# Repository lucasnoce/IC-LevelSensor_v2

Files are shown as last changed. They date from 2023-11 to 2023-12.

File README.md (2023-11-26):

# IC-LevelSensor_v2
This is version 2 of an IoT device designed to measure water levels using an ultrasonic sensing module and transmit the acquired data via NBIoT.

## Summary
Similar to version 1, the system employs an AJ-SR04M ultrasonic sensing module now connected to a STM32L476RGT6 microcontroller. This module measures the time interval it takes for an ultrasonic wave to travel from the transducer to the water level and back. By calculating the distance based on the time duration, the speed of sound, and dividing the result by 2, the accurate water level is determined. As the speed of sound varies based on factors such as temperature, humidity, and pressure, a SHT31-DIS sensor is incorporated to measure temperature and humidity (pressure is assumed constant). This additional information allows for precise estimation of the speed of sound just before each distance measurement is taken.

To transmit data to the TagoIO platform, a SIM7020 NBIoT module is utilized, employing the MQTT protocol. This facilitates the configuration of a comprehensive dashboard displaying variations in water and battery levels, local temperature and humidity over time, making it an excellent solution for monitoring purposes.

The device is specifically designed for deployment in remote environments and operates on battery power. Due to this constraint, the system primarily operates in low-power mode and wakes up periodically. In this initial version of the device, the wake-up period is intentionally kept small, and collected data is transmitted during each wake-up event via NBIoT. This design choice aims to facilitate easier debugging and testing of the device's functionality. Because it is designed to be battery powered, the device can monitor battery voltage through the microcontroller's ADC.

## Designed PCB
The following image shows the designed PCB layout. It incorporates the SMT32, SHT31, SIM7020E and its adjacent circuitry onto the layout, only leaving the AJ-SR04M as an external module. The PCB features a P-Channel MOSFET at power input for low power reverse polarity protection, a selectable current sensing shunt resistor and ESD protection on the USB connector, SIM Card socket and SIM7020 power input tantalum capacitors. Also features IPEX connector for external antenna with impedance matched trace. The board works on 3.3V and can be powered either by 1.5V batteries such as AAA (through TPS613221ADBV DC-DC boost converter) or by the Micro USB type B (through AMS1117-3.3 regulator).

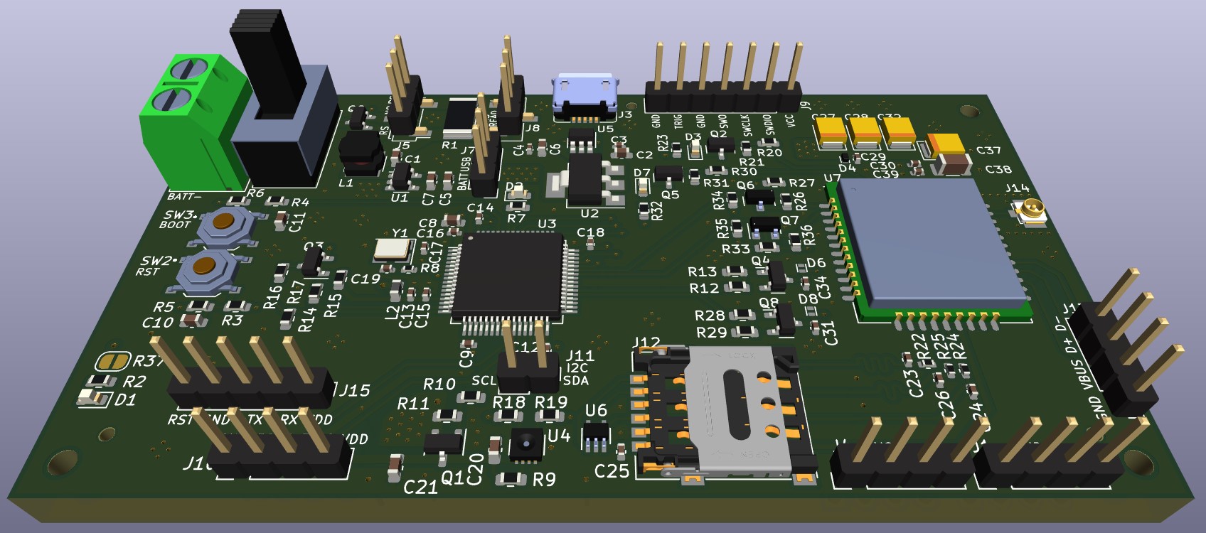
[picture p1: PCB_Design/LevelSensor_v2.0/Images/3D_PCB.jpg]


## Software
Still under development, all drivers and functionalities will be implemented from scratch through STM32CubeIDE.

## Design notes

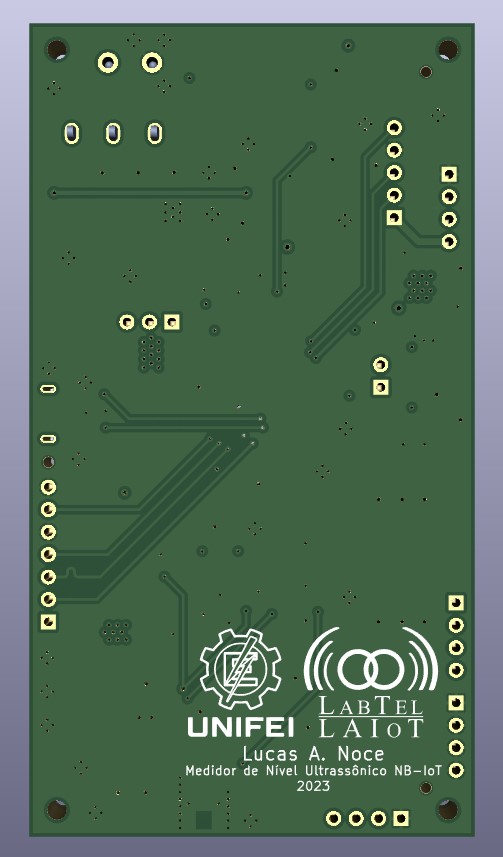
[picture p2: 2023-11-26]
PCB_Design/LevelSensor_v2.0/Images/3D_PCB_back.jpg

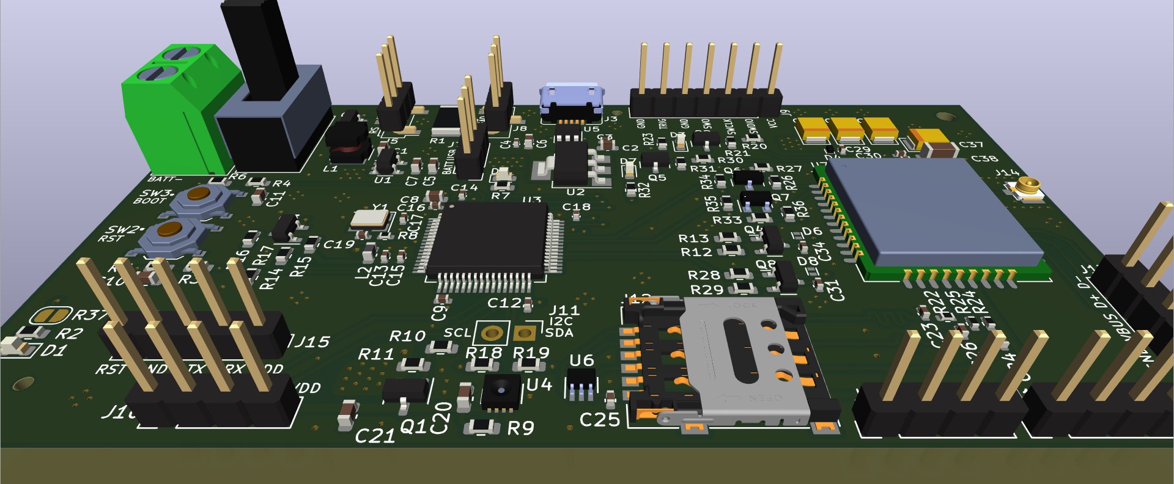
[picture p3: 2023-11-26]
PCB_Design/LevelSensor_v2.0/Images/3D_PCB_2.jpg

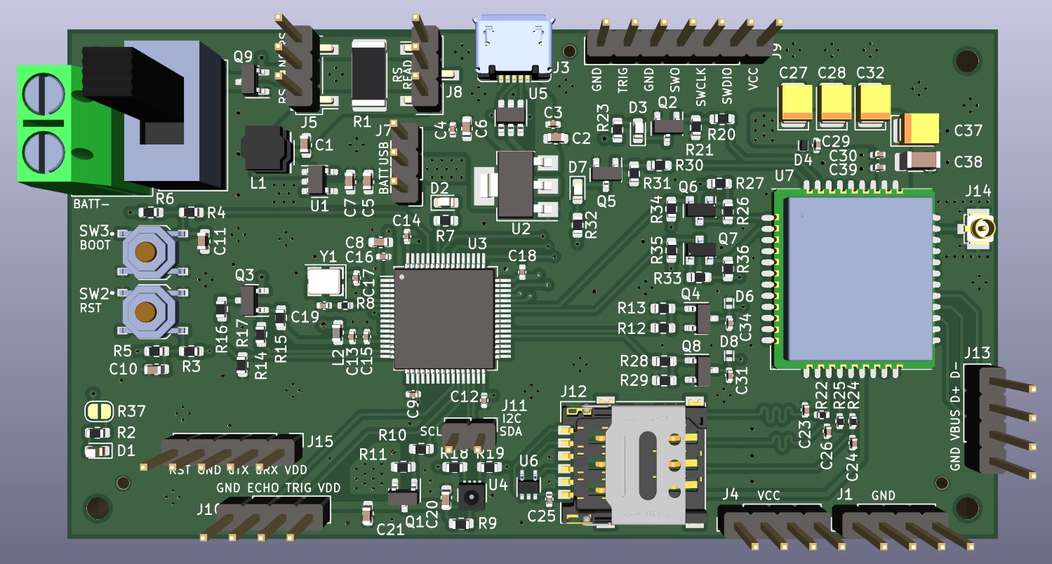
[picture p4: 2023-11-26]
PCB_Design/LevelSensor_v2.0/Images/3D_PCB_front.jpg

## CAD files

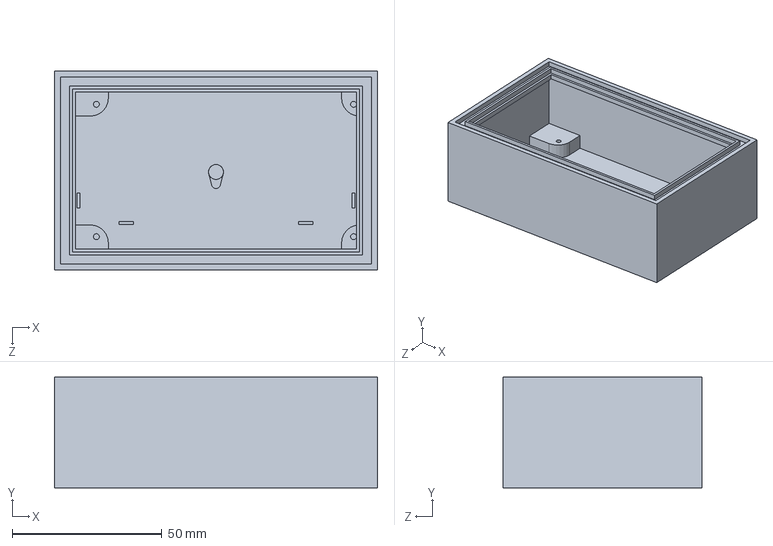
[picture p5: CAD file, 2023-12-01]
3D_Case/Caixa_v1.SLDPRT
108.0 x 37.0 x 66.4 mm

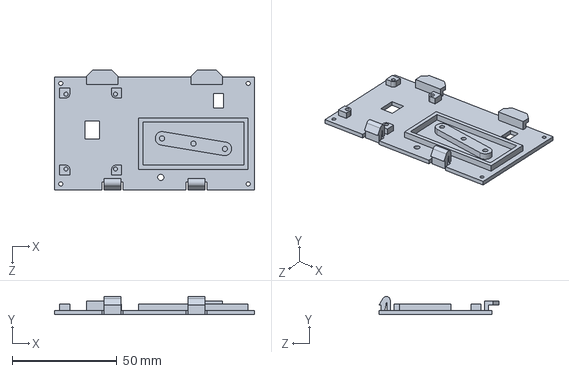
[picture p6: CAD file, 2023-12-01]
3D_Case/Tampa_v1.SLDPRT
95.5 x 8.66 x 57.5 mm

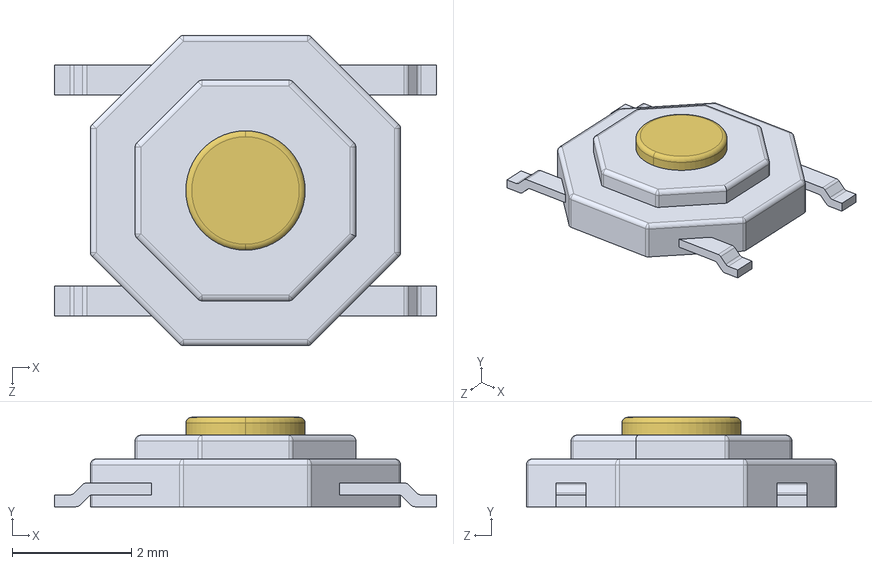
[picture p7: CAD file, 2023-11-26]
PCB_Design/LevelSensor_v2.0/3D_Models/Push-button_SMD_SKQGAFE010.STEP
6.40 x 1.50 x 5.20 mm

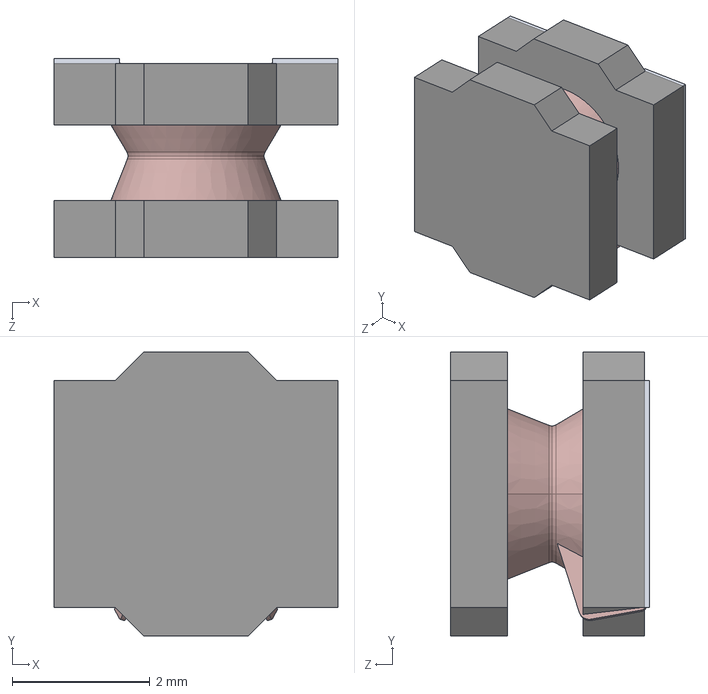
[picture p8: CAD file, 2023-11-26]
PCB_Design/LevelSensor_v2.0/3D_Models/L_FNR4030S2R2MT.STEP
4.12 x 4.12 x 2.89 mm

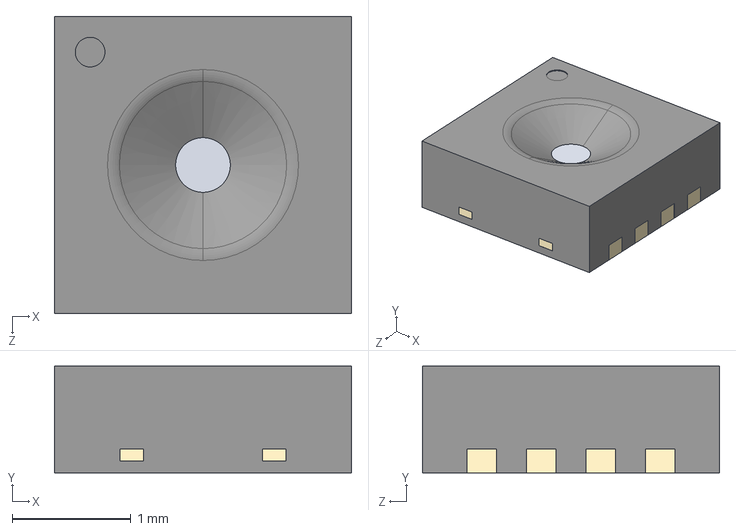
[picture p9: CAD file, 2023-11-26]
PCB_Design/LevelSensor_v2.0/3D_Models/SHT31-DIS_DFN-8.STEP
2.50 x 0.9 x 2.50 mm

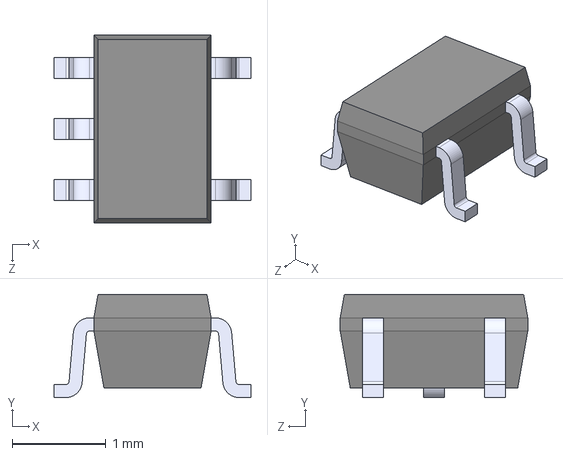
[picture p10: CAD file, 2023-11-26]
PCB_Design/LevelSensor_v2.0/3D_Models/ESDA6V1W5--3DModel-STEP-56544.STEP
2.10 x 1.10 x 2.00 mm

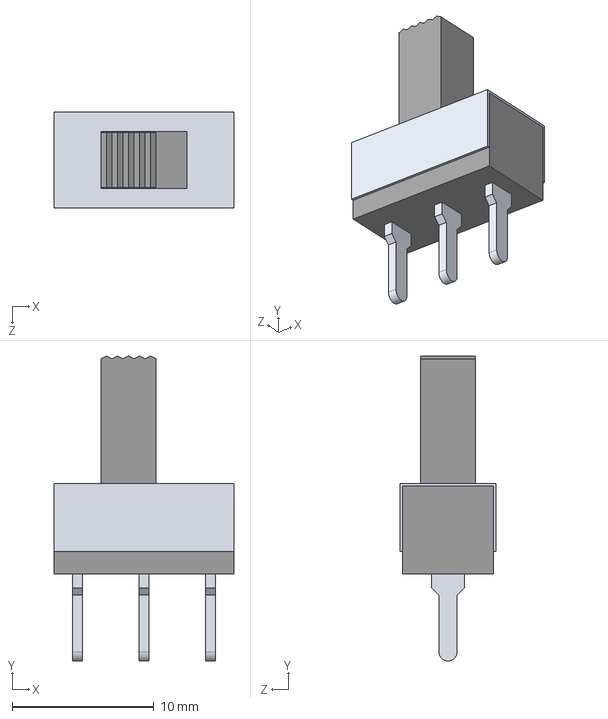
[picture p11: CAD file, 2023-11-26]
PCB_Design/LevelSensor_v2.0/3D_Models/SPDT.STEP
12.7 x 21.5 x 6.80 mm

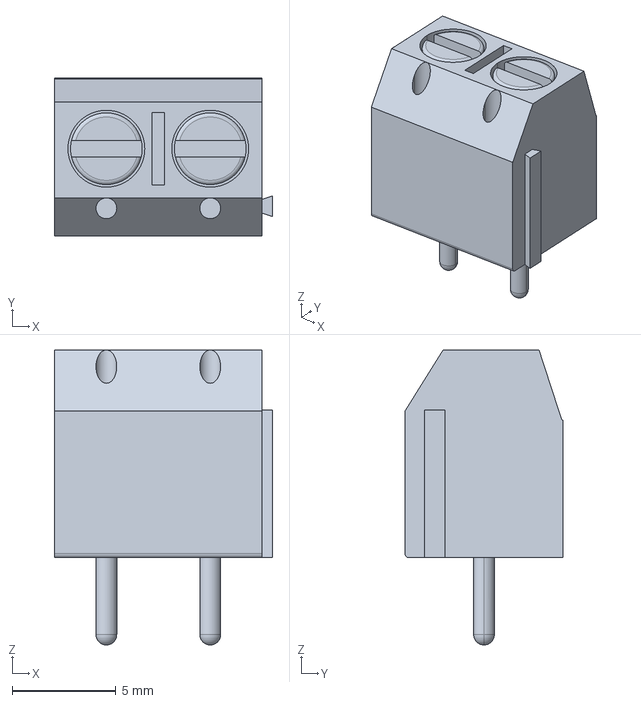
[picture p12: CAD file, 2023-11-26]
PCB_Design/LevelSensor_v2.0/3D_Models/RND 205-301-5.0-02P--3DModel-STEP-697569.STEP
10.5 x 7.60 x 14.2 mm

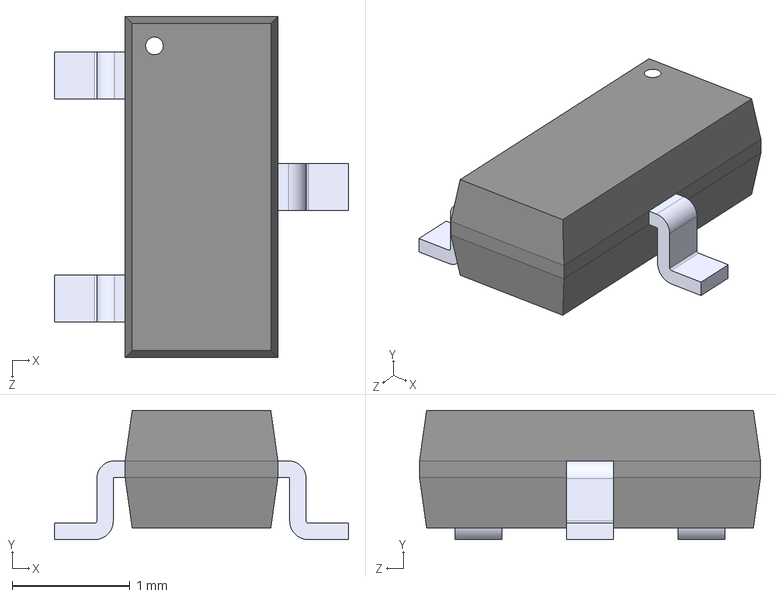
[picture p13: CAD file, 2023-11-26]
PCB_Design/LevelSensor_v2.0/3D_Models/MMBT3904.STEP
2.50 x 1.10 x 2.90 mm

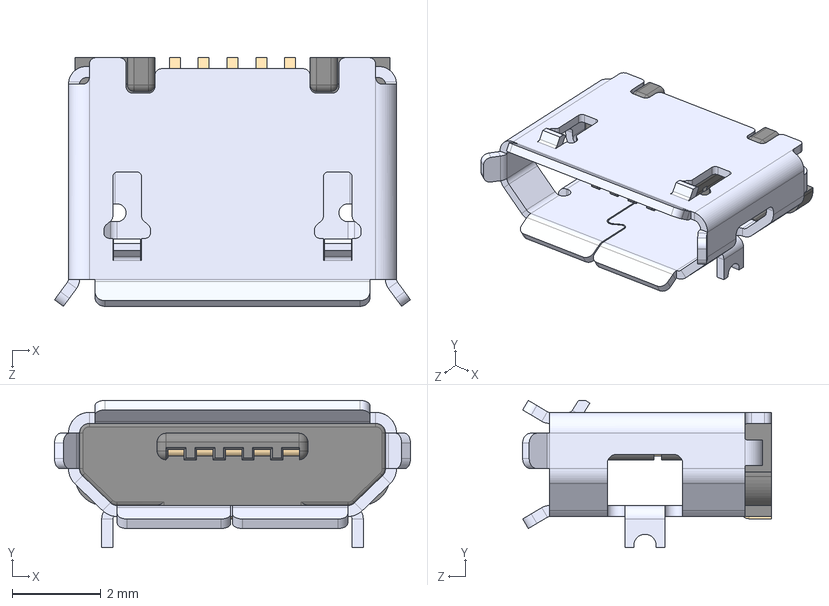
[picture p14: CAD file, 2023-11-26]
PCB_Design/LevelSensor_v2.0/3D_Models/USB-MR-D-015--3DModel-STEP-269445.STEP
8.03 x 3.32 x 5.61 mm

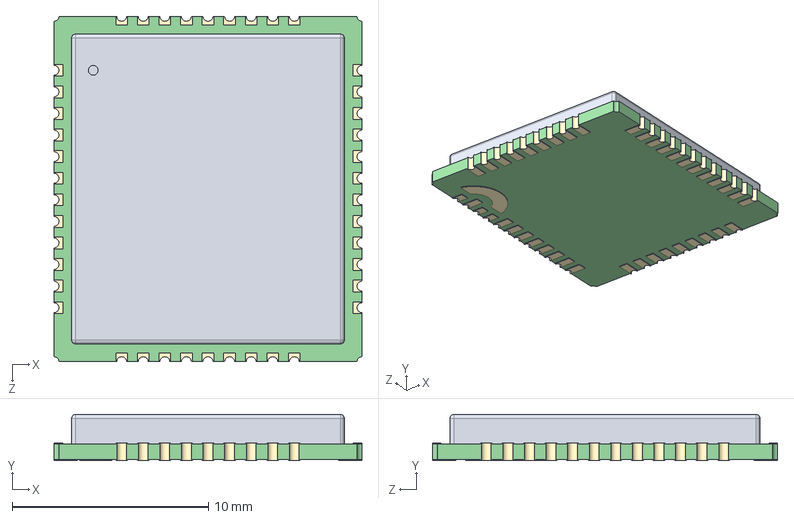
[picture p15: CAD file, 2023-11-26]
PCB_Design/LevelSensor_v2.0/3D_Models/SIM7020E.STEP
15.7 x 2.35 x 17.6 mm

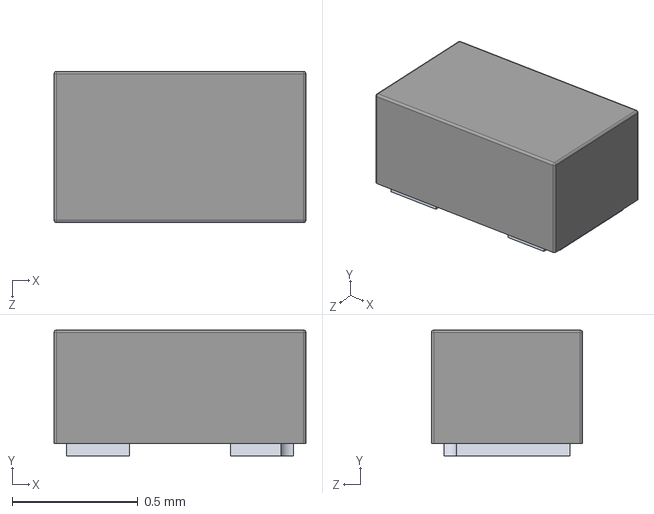
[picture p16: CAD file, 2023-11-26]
PCB_Design/LevelSensor_v2.0/3D_Models/DFN1006-2L.STEP
1.00 x 0.5 x 0.6 mm

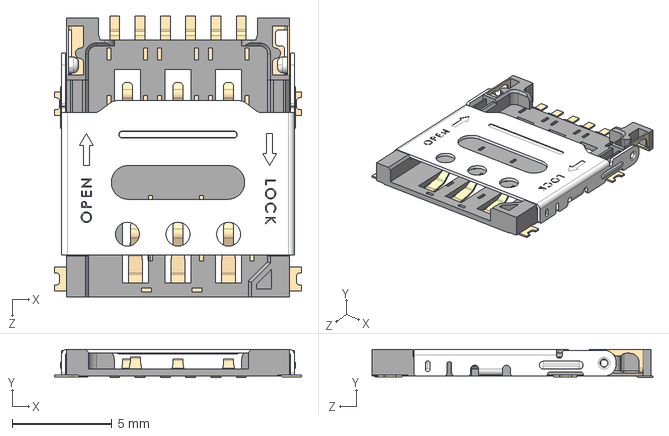
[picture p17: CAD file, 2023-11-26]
PCB_Design/LevelSensor_v2.0/3D_Models/sim8060-6-0-14-00-a_reva.step
12.4 x 1.43 x 14.1 mm
Housing1_without switch

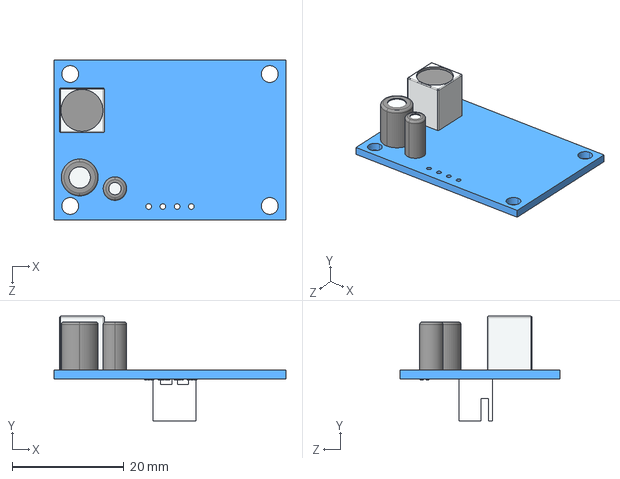
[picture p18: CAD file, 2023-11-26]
PCB_Design/LevelSensor_v2.0/3D_Models/AJ-SR04M.STEP
41.5 x 18.7 x 28.6 mm

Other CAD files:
PCB_Design/LevelSensor_v2.0/3D_Models/RND 205-301-5.0-02P--3DModel-STEP-697569_col.STEP
PCB_Design/LevelSensor_v2.0/3D_Models/10118192C.stp

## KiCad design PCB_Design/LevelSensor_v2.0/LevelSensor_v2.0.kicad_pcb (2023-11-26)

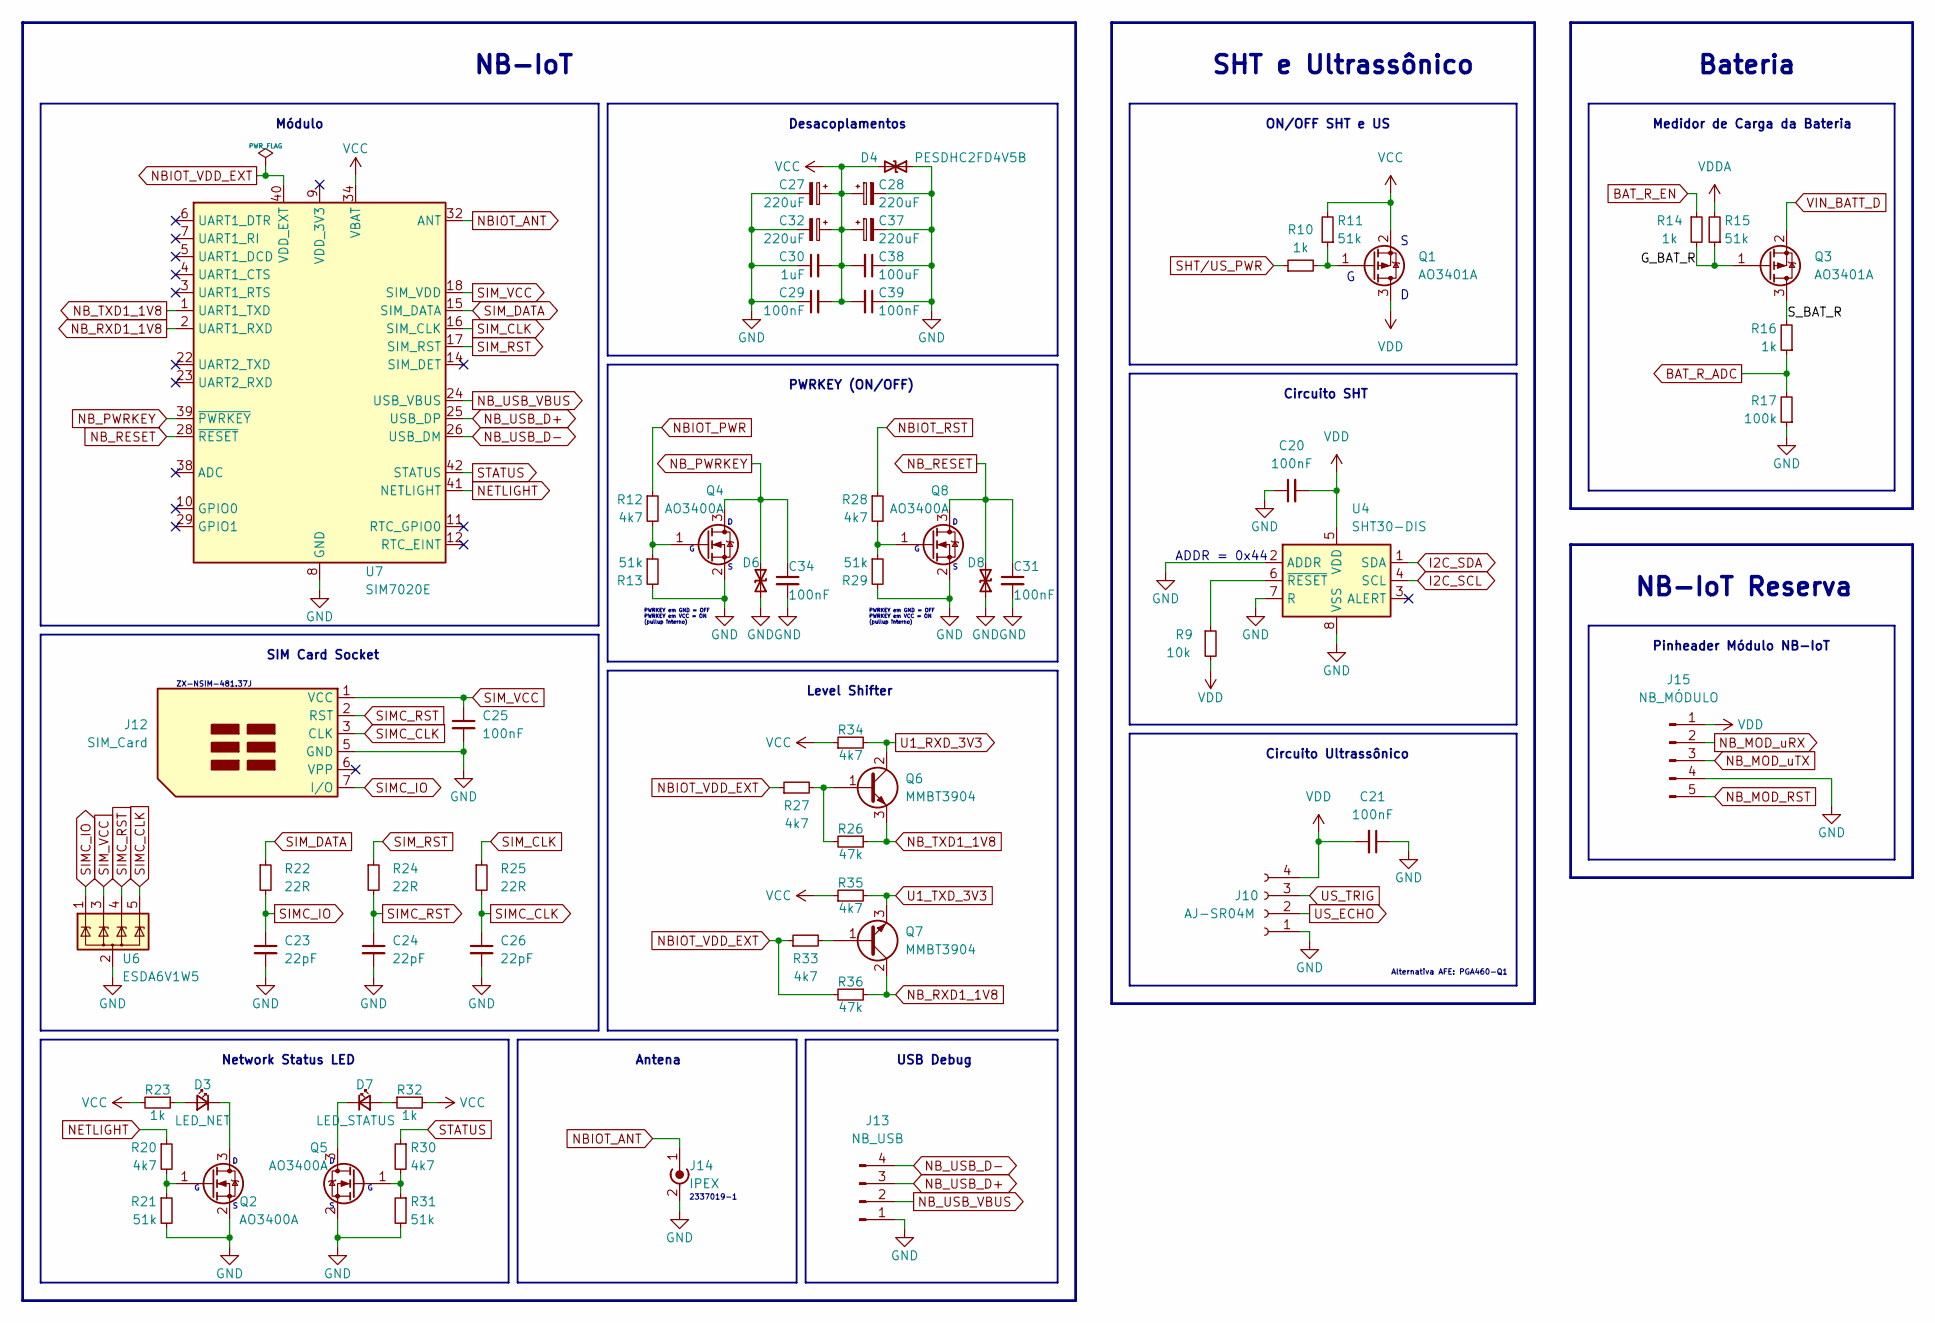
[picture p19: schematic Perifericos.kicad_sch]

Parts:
C20, C21: 100nF; C_0603_1608Metric; LCSC Part Number C14663
C23, C24, C26: 22pF; C_0402_1005Metric; LCSC Part Number C1555
C25, C29, C31, C34, C39: 100nF; C_0402_1005Metric; LCSC Part Number C1525
C27, C28, C32, C37: 220uF; CP_EIA-3528-12_Kemet-T
C30: 1uF; C_0402_1005Metric; LCSC Part Number C52923
C38: 100uF; C_1206_3216Metric; LCSC Part Number C15008
D3: LED_NET; LED_0603_1608Metric; LCSC Part Number C2286
D4, D6, D8: PESDHC2FD4V5B; D_TVS_DFN1006-2L
D7: LED_STATUS; LED_0603_1608Metric; LCSC Part Number C72041
J10: AJ-SR04M
J12: SIM_Card; NanoSIMCard-Socket_ZX-NSIM-281.4J
J13: NB_USB; PinHeader_1x04_P2.54mm_Vertical
J14: IPEX; Conn_RF_Receptacle_SMT-TE_2337019-1
J15: NB_MÓDULO; PinHeader_1x05_P2.54mm_Vertical
Q1, Q3: AO3401A; SOT-23; LCSC Part Number C15127
Q2, Q4, Q5, Q8: AO3400A; SOT-23; LCSC Part Number C20917
Q6, Q7: MMBT3904; TBJ_SOT-23; LCSC Part Number C20526
R9: 10k; R_0603_1608Metric; LCSC Part Number C25804
R10, R14, R16, R23, R32: 1k; R_0603_1608Metric; LCSC Part Number C21190
R11, R13, R15, R21, R29, R31: 51k; R_0603_1608Metric; LCSC Part Number C23196
R12, R20, R27, R28, R30, R33, R34, R35: 4k7; R_0603_1608Metric; LCSC Part Number C23162
R17: 100k; R_0603_1608Metric; LCSC Part Number C25803
R22, R24, R25: 22R; R_0402_1005Metric; LCSC Part Number C25092
R26, R36: 47k; R_0603_1608Metric; LCSC Part Number C25819
U4: SHT30-DIS; Sensirion_DFN-8-1EP_2.5x2.5mm_P0.5mm_EP1.1x1.7mm; LCSC Part Number C2687423
U6: ESDA6V1W5; SOT323-5L; LCSC Part Number C167129
U7: SIM7020E; SIMCom_SIM800C; LCSC Part Number C194746

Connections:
/Perifericos/G_BAT_R: Q3.1 (G), R14.2, R15.1
/Perifericos/S_BAT_R: Q3.3 (D), R16.2
BAT_R_ADC: R16.1, R17.2; also elsewhere on the board
BAT_R_EN: R14.1; also elsewhere on the board
GND: C20.1, C21.1, C23.2, C24.2, C25.2, C26.2, C27.2, C28.2, C29.1, C30.1, C31.2, C32.2, C34.2, C37.2, C38.1, C39.1, D4.1 (A1), D6.1 (A1), D8.1 (A1), J10.1, J12.5 (GND), J13.1, J14.2 (Ext), J15.4, Q2.2 (S), Q4.2 (S), Q5.2 (S), Q8.2 (S), R13.2, R17.1, R21.2, R29.2, R31.2, U4.2 (ADDR), U4.7 (R), U4.8 (VSS), U4.9 (VSS), U6.2 (GND), U7.8 (GND), U7.13 (GND), U7.19 (GND), U7.21 (GND), U7.27 (GND), U7.30 (GND), U7.31 (GND), U7.33 (GND), U7.36 (GND), U7.37 (GND); also elsewhere on the board
I2C_SCL: U4.4 (SCL); also elsewhere on the board
I2C_SDA: U4.1 (SDA); also elsewhere on the board
NBIOT_ANT: J14.1 (In), U7.32 (ANT)
NBIOT_PWR: R12.1; also elsewhere on the board
NBIOT_RST: R28.1; also elsewhere on the board
NBIOT_VDD_EXT: R27.1, R33.1, R36.2, U7.40 (VDD_EXT)
NB_MOD_RST: J15.5; also elsewhere on the board
NB_MOD_uRX: J15.2; also elsewhere on the board
NB_MOD_uTX: J15.3; also elsewhere on the board
NB_PWRKEY: C34.1, D6.2 (A2), Q4.3 (D), U7.39 (~PWRKEY)
NB_RESET: C31.1, D8.2 (A2), Q8.3 (D), U7.28 (~RESET)
NB_RXD1_1V8: Q7.2 (C), R36.1, U7.2 (UART1_RXD)
NB_TXD1_1V8: Q6.3 (E), R26.1, U7.1 (UART1_TXD)
NB_USB_D+: J13.3, U7.25 (USB_DP)
NB_USB_D-: J13.4, U7.26 (USB_DM)
NB_USB_VBUS: J13.2, U7.24 (USB_VBUS)
NETLIGHT: R20.1, U7.41 (NETLIGHT)
unnamed: D3.1 (K), Q2.3 (D)
unnamed: D3.2 (A), R23.1
unnamed: D7.1 (K), Q5.3 (D)
unnamed: D7.2 (A), R32.1
unnamed: Q1.1 (G), R10.2, R11.1
unnamed: Q2.1 (G), R20.2, R21.1
unnamed: Q4.1 (G), R12.2, R13.1
unnamed: Q5.1 (G), R30.2, R31.1
unnamed: Q6.1 (B), R26.2, R27.2
unnamed: Q7.1 (B), R33.2
unnamed: Q8.1 (G), R28.2, R29.1
unnamed: R9.1, U4.6 (~RESET)
SHT/US_PWR: R10.1; also elsewhere on the board
SIMC_CLK: C26.1, J12.3 (CLK), R25.2, U6.5 (IO5)
SIMC_IO: C23.1, J12.7 (I/O), R22.2, U6.1 (IO1)
SIMC_RST: C24.1, J12.2 (RST), R24.2, U6.4 (IO4)
SIM_CLK: R25.1, U7.16 (SIM_CLK)
SIM_DATA: R22.1, U7.15 (SIM_DATA)
SIM_RST: R24.1, U7.17 (SIM_RST)
SIM_VCC: C25.1, J12.1 (VCC), U6.3 (IO2), U7.18 (SIM_VDD)
STATUS: R30.1, U7.42 (STATUS)
U1_RXD_3V3: Q6.2 (C), R34.2; also elsewhere on the board
U1_TXD_3V3: Q7.3 (E), R35.2; also elsewhere on the board
US_ECHO: J10.2; also elsewhere on the board
US_TRIG: J10.3; also elsewhere on the board
VCC: C27.1, C28.1, C29.2, C30.2, C32.1, C37.1, C38.2, C39.2, D4.2 (A2), Q1.2 (S), R11.2, R23.2, R32.2, R34.1, R35.1, U7.34 (VBAT), U7.35 (VBAT); also elsewhere on the board
VDD: C20.2, C21.2, J10.4, J15.1, Q1.3 (D), R9.2, U4.5 (VDD)
VDDA: R15.2; also elsewhere on the board
VIN_BATT_D: Q3.2 (S); also elsewhere on the board

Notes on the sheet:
Circuito Ultrassônico
PWRKEY (ON/OFF)
Circuito SHT
PWRKEY em GND = OFF PWRKEY em VCC = ON (pullup interno)
Pinheader Módulo NB-IoT
ON/OFF SHT e US
2337019-1
Network Status LED
USB Debug
NB-IoT Reserva
Antena
NB-IoT
Bateria
Level Shifter
SIM Card Socket
Medidor de Carga da Bateria
SHT e Ultrassônico
Desacoplamentos
ZX-NSIM-481.37J
Alternativa AFE: PGA460-Q1
ADDR = 0x44
Módulo

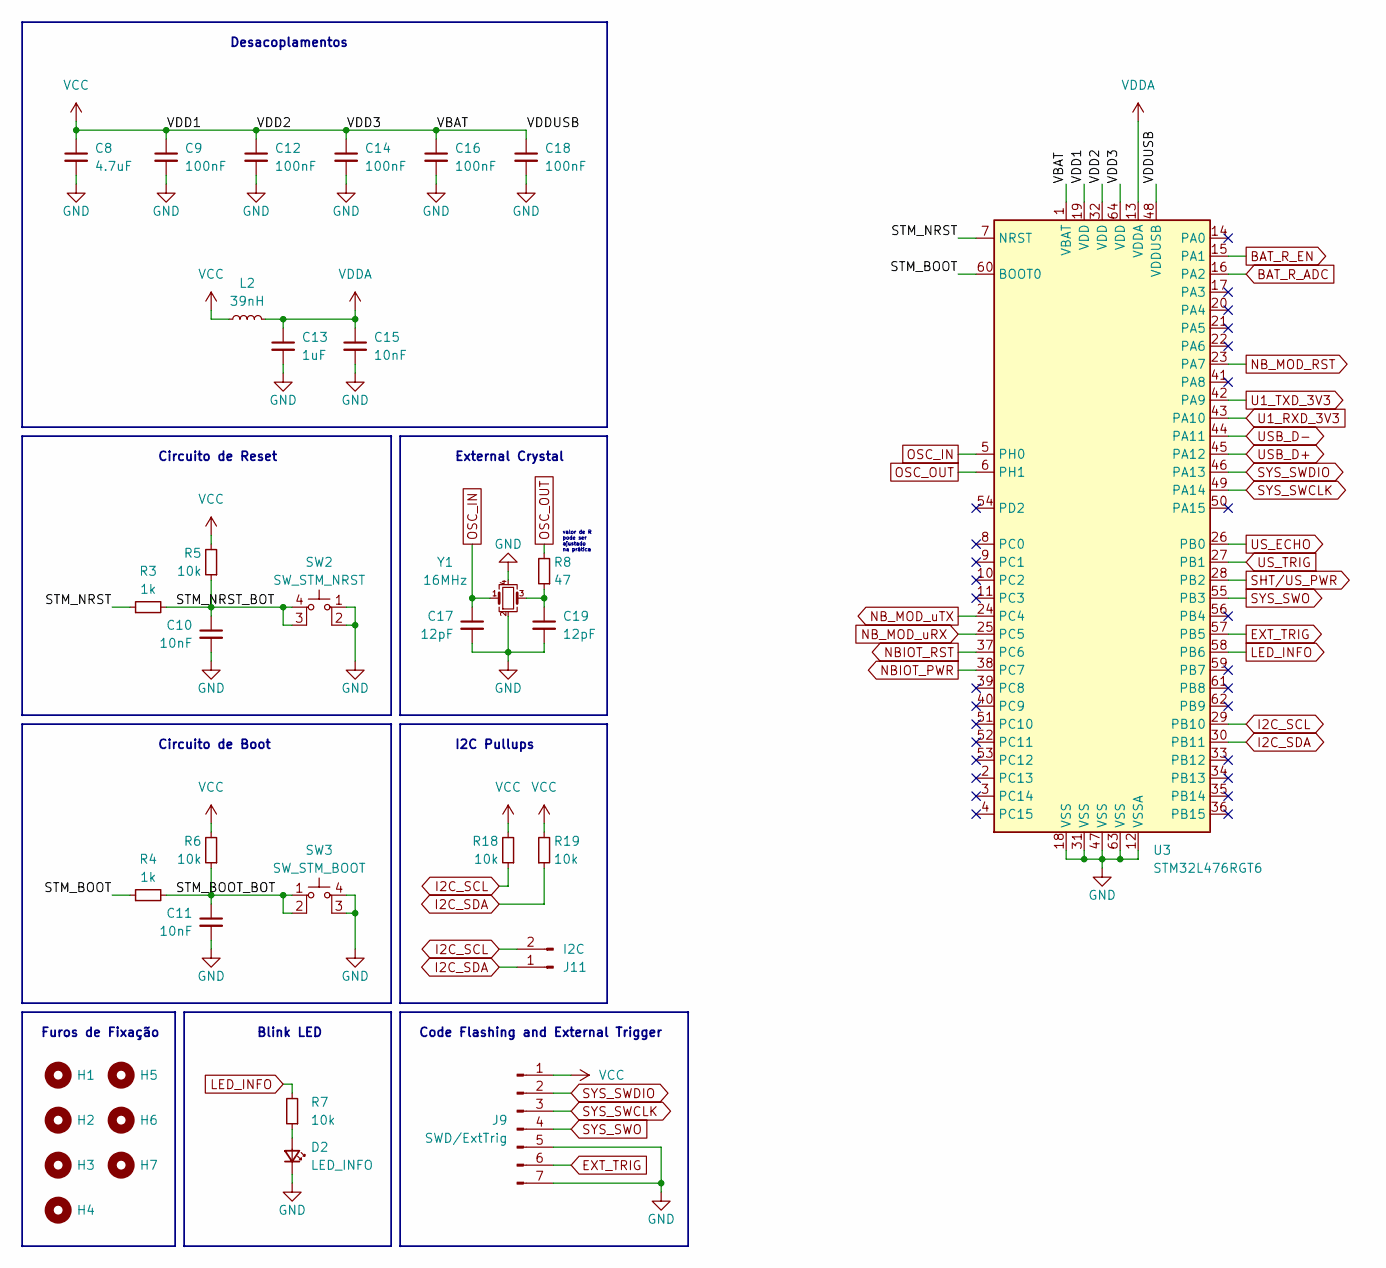
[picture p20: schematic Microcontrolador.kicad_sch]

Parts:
C8: 4.7uF; C_0603_1608Metric; LCSC Part Number C19666
C9, C12, C14, C16, C18: 100nF; C_0402_1005Metric; LCSC Part Number C1525
C10, C11: 10nF; C_0603_1608Metric; LCSC Part Number C57112
C13: 1uF; C_0402_1005Metric; LCSC Part Number C52923
C15: 10nF; C_0402_1005Metric; LCSC Part Number C15195
C17, C19: 12pF; C_0402_1005Metric; LCSC Part Number C1547
D2: LED_INFO; LED_0603_1608Metric; LCSC Part Number C72041
H1, H2, H3, H4: SupPCB; MountingHole_2.2mm_M2
H5, H6, H7: ToolingHole; JLCPCB_ToolingHole
J9: SWD/ExtTrig; PinHeader_1x07_P2.54mm_Vertical
J11: I2C; PinHeader_1x02_P2.54mm_Vertical
L2: 39nH; L_0603_1608Metric
R3, R4: 1k; R_0603_1608Metric; LCSC Part Number C21190
R5, R6, R7, R18, R19: 10k; R_0603_1608Metric; LCSC Part Number C25804
R8: 47; R_0402_1005Metric; LCSC Part Number C25118
SW2: SW_STM_NRST; SW_TS-1187A-B-A-B; LCSC Part Number C318884
SW3: SW_STM_BOOT; SW_TS-1187A-B-A-B; LCSC Part Number C318884
U3: STM32L476RGT6; LQFP-64_10x10mm_P0.5mm; LCSC Part Number C74797
Y1: 16MHz; Crystal_SMD_Abracon_ABM8G-4Pin_3.2x2.5mm; LCSC Part Number C13738

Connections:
/Microcontrolador/STM_BOOT: R4.1, U3.60 (BOOT0)
/Microcontrolador/STM_BOOT_BOT: C11.1, R4.2, R6.1, SW3.1, SW3.2
/Microcontrolador/STM_NRST: R3.1, U3.7 (NRST)
/Microcontrolador/STM_NRST_BOT: C10.1, R3.2, R5.1, SW2.3 (K), SW2.4 (A)
BAT_R_ADC: U3.16 (PA2); also elsewhere on the board
BAT_R_EN: U3.15 (PA1); also elsewhere on the board
EXT_TRIG: J9.6, U3.57 (PB5)
GND: C8.2, C9.2, C10.2, C11.2, C12.2, C13.2, C14.2, C15.2, C16.2, C17.2, C18.2, C19.2, D2.1 (K), J9.5, J9.7, SW2.1, SW2.2, SW3.3 (K), SW3.4 (A), U3.12 (VSSA), U3.18 (VSS), U3.31 (VSS), U3.47 (VSS), U3.63 (VSS), Y1.2, Y1.4; also elsewhere on the board
I2C_SCL: J11.2, R18.1, U3.29 (PB10); also elsewhere on the board
I2C_SDA: J11.1, R19.1, U3.30 (PB11); also elsewhere on the board
LED_INFO: R7.2, U3.58 (PB6)
NBIOT_PWR: U3.38 (PC7); also elsewhere on the board
NBIOT_RST: U3.37 (PC6); also elsewhere on the board
NB_MOD_RST: U3.23 (PA7); also elsewhere on the board
NB_MOD_uRX: U3.25 (PC5); also elsewhere on the board
NB_MOD_uTX: U3.24 (PC4); also elsewhere on the board
unnamed: C19.1, R8.1, Y1.3
unnamed: D2.2 (A), R7.1
OSC_IN: C17.1, U3.5 (PH0), Y1.1
OSC_OUT: R8.2, U3.6 (PH1)
SHT/US_PWR: U3.28 (PB2); also elsewhere on the board
SYS_SWCLK: J9.3, U3.49 (PA14)
SYS_SWDIO: J9.2, U3.46 (PA13)
SYS_SWO: J9.4, U3.55 (PB3)
U1_RXD_3V3: U3.43 (PA10); also elsewhere on the board
U1_TXD_3V3: U3.42 (PA9); also elsewhere on the board
USB_D+: U3.45 (PA12); also elsewhere on the board
USB_D-: U3.44 (PA11); also elsewhere on the board
US_ECHO: U3.26 (PB0); also elsewhere on the board
US_TRIG: U3.27 (PB1); also elsewhere on the board
VCC: C8.1, C9.1, C12.1, C14.1, C16.1, C18.1, J9.1, L2.1, R5.2, R6.2, R18.2, R19.2, U3.1 (VBAT), U3.19 (VDD), U3.32 (VDD), U3.48 (VDDUSB), U3.64 (VDD); also elsewhere on the board
VDDA: C13.1, C15.1, L2.2, U3.13 (VDDA); also elsewhere on the board

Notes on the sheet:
I2C Pullups
External Crystal
Desacoplamentos
Circuito de Boot
Blink LED
valor de R pode ser ajustado na prática
Furos de Fixação
Circuito de Reset
Code Flashing and External Trigger

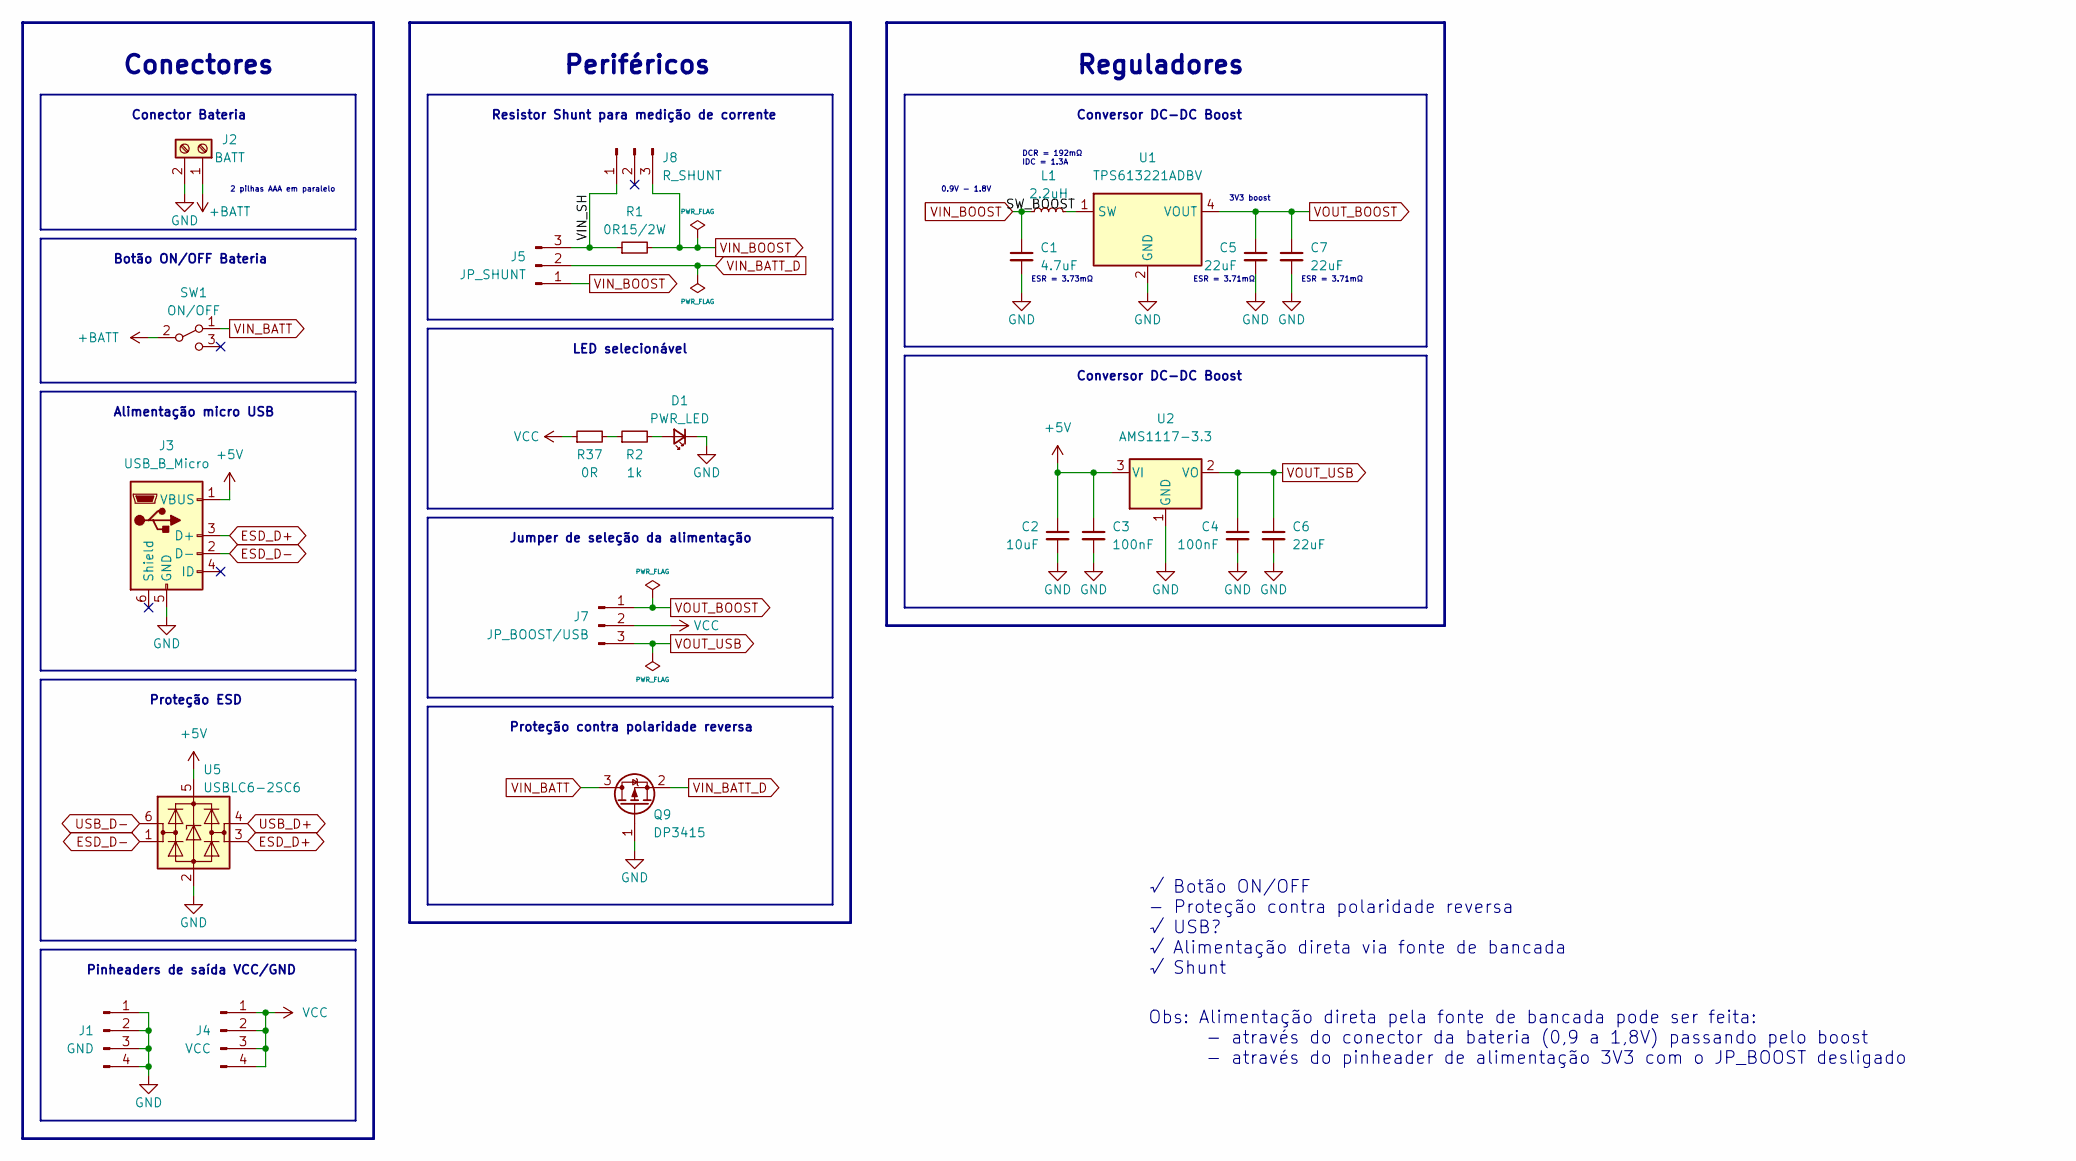
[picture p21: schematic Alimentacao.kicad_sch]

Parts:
C1: 4.7uF; C_0603_1608Metric; LCSC Part Number C19666
C2: 10uF; C_0603_1608Metric; LCSC Part Number C19702
C3, C4: 100nF; C_0402_1005Metric; LCSC Part Number C1525
C5, C6, C7: 22uF; C_0603_1608Metric; LCSC Part Number C59461
D1: PWR_LED; LED_0603_1608Metric; LCSC Part Number C2286
J1: GND; PinHeader_1x04_P2.54mm_Vertical
J2: BATT; ScrewTerminal_1x2P_P5mm
J3: USB_B_Micro; USB_Micro_B-Dealon_USB-MR-D-015
J4: VCC; PinHeader_1x04_P2.54mm_Vertical
J5: JP_SHUNT; PinHeader_1x03_P2.54mm_Vertical_SMD_Pin1Left
J7: JP_BOOST/USB; PinHeader_1x03_P2.54mm_Vertical
J8: R_SHUNT; PinHeader_1x03_P2.54mm_Vertical_SMD_Pin1Left
L1: 2.2uH; L_SMD-FNR4030S2R2MT
Q9: DP3415; PMOS_DP3415_SOT-23; LCSC Part Number C15127
R1: 0R15/2W; R_2512_6332Metric
R2: 1k; R_0603_1608Metric; LCSC Part Number C21190
R37: 0R; SolderJumper-2_P1.3mm_Open_RoundedPad1.0x1.5mm
SW1: ON/OFF; SW_SPDT_SS-12D10-G090
U1: TPS613221ADBV; SOT-23-5; LCSC Part Number C2070813
U2: AMS1117-3.3; SOT-223-3_TabPin2; LCSC Part Number C6186
U5: USBLC6-2SC6; SOT-23-6

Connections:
+5V: C2.1, C3.1, J3.1 (VBUS), U2.3 (VI), U5.5 (VBUS)
+BATT: J2.1, SW1.2 (B)
/Alimentacao/SW_BOOST: L1.2, U1.1 (SW)
/Alimentacao/VIN_SH: J5.3, J8.1, R1.1
ESD_D+: J3.3 (D+), U5.3 (I/O2)
ESD_D-: J3.2 (D-), U5.1 (I/O1)
GND: C1.2, C2.2, C3.2, C4.2, C5.2, C6.2, C7.2, D1.1 (K), J1.1, J1.2, J1.3, J1.4, J2.2, J3.5 (GND), Q9.1 (G), U1.2 (GND), U2.1 (GND), U5.2 (GND); also elsewhere on the board
unnamed: D1.2 (A), R2.2
unnamed: R2.1, R37.2
USB_D+: U5.4 (I/O2); also elsewhere on the board
USB_D-: U5.6 (I/O1); also elsewhere on the board
VCC: J4.1, J4.2, J4.3, J4.4, J7.2, R37.1; also elsewhere on the board
VIN_BATT: Q9.3 (D), SW1.1 (A)
VIN_BATT_D: J5.2, Q9.2 (S); also elsewhere on the board
VIN_BOOST: C1.1, J5.1, J8.3, L1.1, R1.2
VOUT_BOOST: C5.1, C7.1, J7.1, U1.4 (VOUT)
VOUT_USB: C4.1, C6.1, J7.3, U2.2 (VO)

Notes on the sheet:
Conectores
Obs: Alimentação direta pela fonte de bancada pode ser feita: - através do conector da bateria (0,9 a 1,8V) passando pelo boost - através do pinheader de alimentação 3V3 com o JP_BOOST desligado
Resistor Shunt para medição de corrente
Jumper de seleção da alimentação
ESR = 3.73mΩ
ESR = 3.71mΩ
Reguladores
Conversor DC-DC Boost
DCR = 192mΩ IDC = 1.3A
3V3 boost
Alimentação micro USB
√ Botão ON/OFF - Proteção contra polaridade reversa √ USB? √ Alimentação direta via fonte de bancada √ Shunt
Botão ON/OFF Bateria
Conector Bateria
0.9V - 1.8V
Proteção ESD
LED selecionável
Pinheaders de saída VCC/GND
2 pilhas AAA em paralelo
Periféricos
Proteção contra polaridade reversa

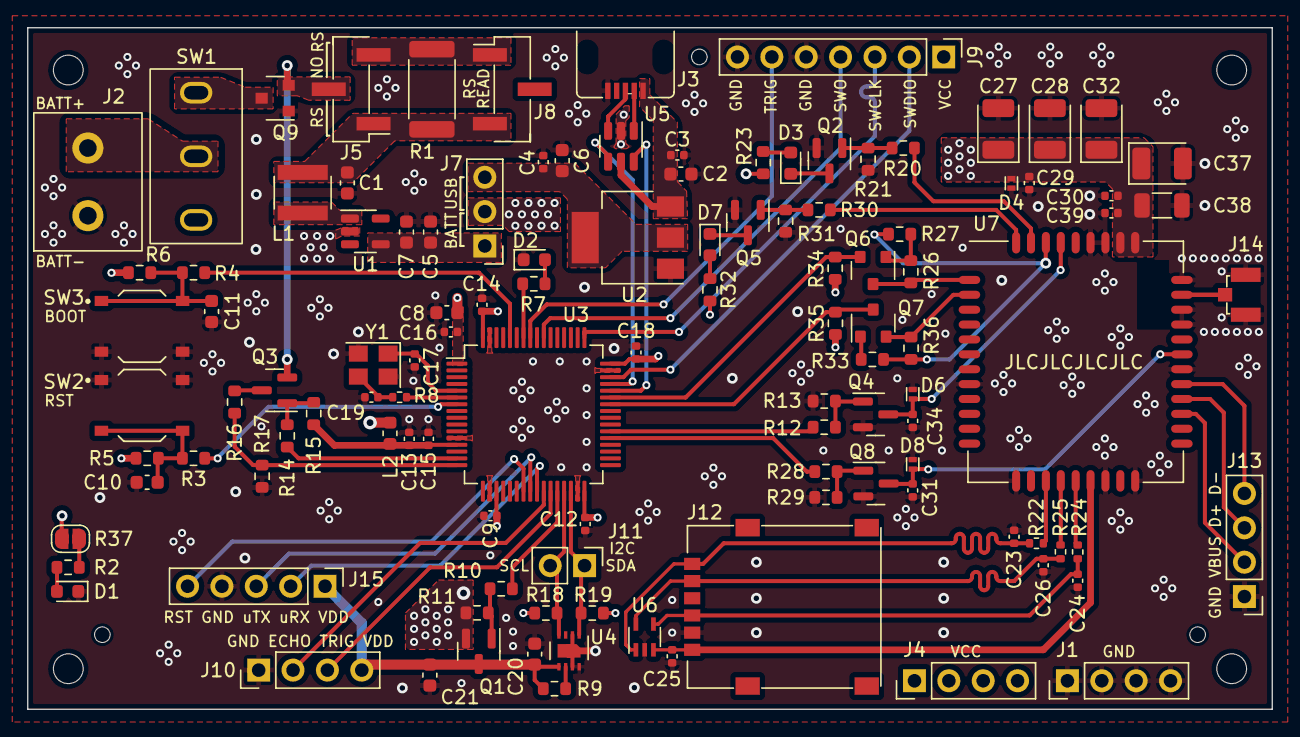
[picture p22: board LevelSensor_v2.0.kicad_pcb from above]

Board: 4 copper layers, 92.0 x 50.4 mm, 122 parts (0 on the bottom side), 78 nets.
